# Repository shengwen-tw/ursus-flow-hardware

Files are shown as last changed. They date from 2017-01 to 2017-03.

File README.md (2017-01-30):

#Ursus-flow

This is the hardware design of Ursus-flow, a computer vision board provide speed estimation for multi-rotor.

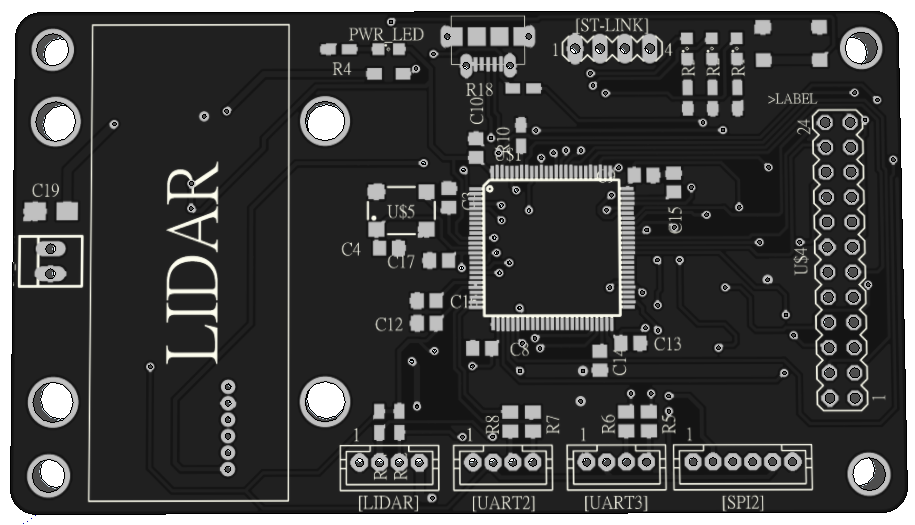
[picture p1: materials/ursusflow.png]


##Specification

**MCU**: STM32F745VETX

**Camera**: MT9v034 (I2C1 and DCMI)

**IMU**: MPU9250 (SPI1)

**Height sensor**: Lidar lite v2 (I2C2)

**USB**: Full Speed USB (USB2.0)

**EEPROM**: AT24C08 (I2C3)

UART2: Data output to flight control board

UART3 and SPI2: alternation

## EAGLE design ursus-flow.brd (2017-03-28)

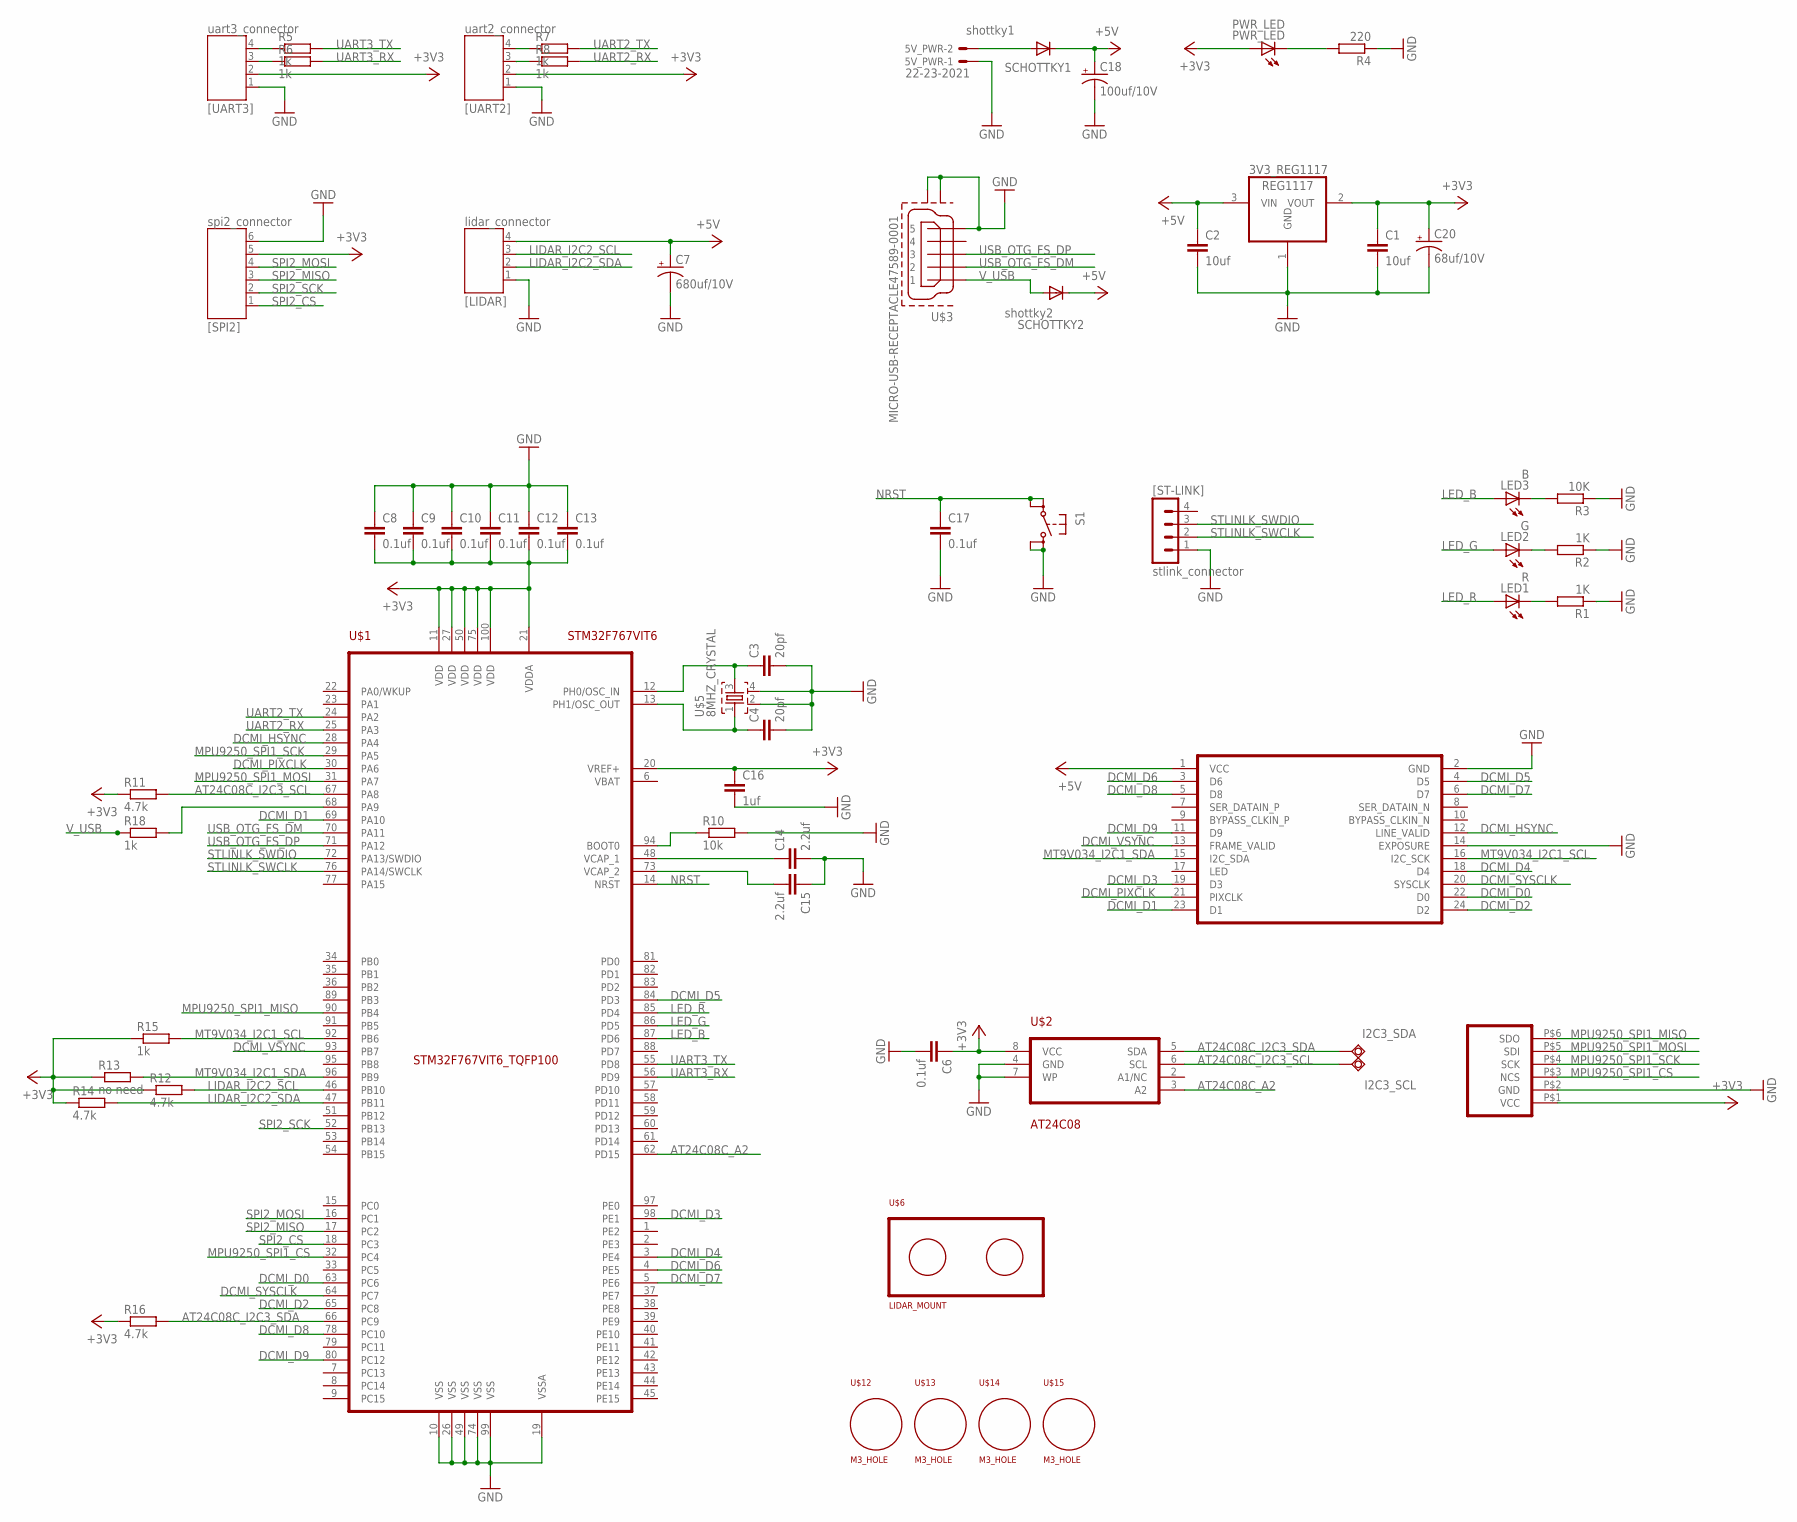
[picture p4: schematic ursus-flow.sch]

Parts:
3V3_REG1117: REG1117; SOT223
5V_PWR: 22-23-2021
C1, C2: 10uf; C0805K
C3, C4: 20pf; C0805
C6, C8, C9, C10, C11, C12, C13, C17: 0.1uf; C0805
C7: 680uf/10V; D/7343-31W
C14, C15: 2.2uf; C0805
C16: 1uf; C0805
C18: 100uf/10V; C/6032-28R
C20: 68uf/10V; B/3528-21W
I2C3_SCL, I2C3_SDA: TPSQTP20SQ; TP20SQ
LED1: R; SML0805
LED2: G; SML0805
LED3: B; SML0805
PWR_LED: PWR_LED; SML0805
R1, R2: 1K; R0805W
R3: 10K; R0805W
R4: 220; R0805W
R5, R6, R7, R8: 1k; M0805
R10: 10k; R0805W
R11, R12, R14, R16: 4.7k; R0805W
R13: no need; R0805W
R15, R18: 1k; R0805W
S1: EVQPSL/Q
SCHOTTKY1: shottky1; SOD323-W
SCHOTTKY2: shottky2; SOD323-W
U$1: STM32F767VIT6
U$2: AT24C08; SO8
U$3: MICRO-USB-RECEPTACLE47589-0001; 47589-0001
U$4: MT9V034_MODULE; MA12-2
U$5: 8MHZ_CRYSTAL
U$6: LIDAR_MOUNT
U$11: MPU9250_BREAKOUT
U$12, U$13, U$14, U$15: M3_HOLE
[LIDAR]: lidar_connector; JST-PH4
[SPI2]: spi2_connector; JST-PH6
[ST-LINK]: stlink_connector; MA04-1
[UART2]: uart2_connector; JST-PH4
[UART3]: uart3_connector; JST-PH4

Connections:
+3V3: 3V3_REG1117.2 (VOUT), C1.1, C6.1, C8.2, C9.2, C10.2, C11.2, C12.2, C13.2, C16.1, C20.+, PWR_LED.A, R11.1, R12.1, R13.1, R14.1, R15.1, R16.1, U$1.11 (VDD), U$1.20 (VREF+), U$1.21 (VDDA), U$1.27 (VDD), U$1.50 (VDD), U$1.75 (VDD), U$1.100 (VDD), U$2.8 (VCC), U$11.P$1 (VCC), [SPI2].5, [UART2].2, [UART3].2
+5V: 3V3_REG1117.3 (VIN), C2.1, C7.+, C18.+, SCHOTTKY1.C, SCHOTTKY2.C, U$4.1 (VCC), [LIDAR].4
AT24C08C_A2: U$1.62 (PD15), U$2.3 (A2)
AT24C08C_I2C3_SCL: I2C3_SCL.TP, R11.2, U$1.67 (PA8), U$2.6 (SCL)
AT24C08C_I2C3_SDA: I2C3_SDA.TP, R16.2, U$1.66 (PC9), U$2.5 (SDA)
DCMI_D0: U$1.63 (PC6), U$4.22 (D0)
DCMI_D1: U$1.69 (PA10), U$4.23 (D1)
DCMI_D2: U$1.65 (PC8), U$4.24 (D2)
DCMI_D3: U$1.98 (PE1), U$4.19 (D3)
DCMI_D4: U$1.3 (PE4), U$4.18 (D4)
DCMI_D5: U$1.84 (PD3), U$4.4 (D5)
DCMI_D6: U$1.4 (PE5), U$4.3 (D6)
DCMI_D7: U$1.5 (PE6), U$4.6 (D7)
DCMI_D8: U$1.78 (PC10), U$4.5 (D8)
DCMI_D9: U$1.80 (PC12), U$4.11 (D9)
DCMI_HSYNC: U$1.28 (PA4), U$4.12 (LINE_VALID)
DCMI_PIXCLK: U$1.30 (PA6), U$4.21 (PIXCLK)
DCMI_SYSCLK: U$1.64 (PC7), U$4.20 (SYSCLK)
DCMI_VSYNC: U$1.93 (PB7), U$4.13 (FRAME_VALID)
GND: 3V3_REG1117.1 (GND), 5V_PWR.1, C1.2, C2.2, C3.2, C4.2, C6.2, C7.-, C8.1, C9.1, C10.1, C11.1, C12.1, C13.1, C14.2, C15.1, C16.2, C17.2, C18.-, C20.-, R1.1, R2.1, R3.1, R4.1, R10.2, S1.B (S), S1.B1 (S1), U$1.10 (VSS), U$1.19 (VSSA), U$1.26 (VSS), U$1.49 (VSS), U$1.74 (VSS), U$1.99 (VSS), U$2.4 (GND), U$2.7 (WP), U$3.5, U$3.CASING1 (GND1), U$3.CASING2 (GND2), U$4.2 (GND), U$4.14 (EXPOSURE), U$5.2, U$5.4, U$11.P$2 (GND), [LIDAR].1, [SPI2].6, [ST-LINK].1, [UART2].1, [UART3].1
LED_B: LED3.A, U$1.87 (PD6)
LED_G: LED2.A, U$1.86 (PD5)
LED_R: LED1.A, U$1.85 (PD4)
LIDAR_I2C2_SCL: R12.2, U$1.46 (PB10), [LIDAR].3
LIDAR_I2C2_SDA: R14.2, U$1.47 (PB11), [LIDAR].2
MPU9250_SPI1_CS: U$1.32 (PC4), U$11.P$3 (NCS)
MPU9250_SPI1_MISO: U$1.90 (PB4), U$11.P$6 (SDO)
MPU9250_SPI1_MOSI: U$1.31 (PA7), U$11.P$5 (SDI)
MPU9250_SPI1_SCK: U$1.29 (PA5), U$11.P$4 (SCK)
MT9V034_I2C1_SCL: R15.2, U$1.92 (PB6), U$4.16 (I2C_SCK)
MT9V034_I2C1_SDA: R13.2, U$1.96 (PB9), U$4.15 (I2C_SDA)
unnamed: LED1.C, R1.2
unnamed: LED2.C, R2.2
unnamed: LED3.C, R3.2
unnamed: PWR_LED.C, R4.2
unnamed: 5V_PWR.2, SCHOTTKY1.A
unnamed: C3.1, U$1.12 (PH0/OSC_IN), U$5.3
unnamed: R5.1, [UART3].4
unnamed: R6.1, [UART3].3
unnamed: R7.1, [UART2].4
unnamed: R8.1, [UART2].3
unnamed: C4.1, U$1.13 (PH1/OSC_OUT), U$5.1
unnamed: C14.1, U$1.48 (VCAP_1)
unnamed: C15.2, U$1.73 (VCAP_2)
unnamed: R10.1, U$1.94 (BOOT0)
unnamed: R18.2, U$1.68 (PA9)
NRST: C17.1, S1.A, S1.A1 (P1), U$1.14 (NRST)
SPI2_CS: U$1.18 (PC3), [SPI2].1
SPI2_MISO: U$1.17 (PC2), [SPI2].3
SPI2_MOSI: U$1.16 (PC1), [SPI2].4
SPI2_SCK: U$1.52 (PB13), [SPI2].2
STLINLK_SWCLK: U$1.76 (PA14/SWCLK), [ST-LINK].2
STLINLK_SWDIO: U$1.72 (PA13/SWDIO), [ST-LINK].3
UART2_RX: R8.2, U$1.25 (PA3)
UART2_TX: R7.2, U$1.24 (PA2)
UART3_RX: R6.2, U$1.56 (PD9)
UART3_TX: R5.2, U$1.55 (PD8)
USB_OTG_FS_DM: U$1.70 (PA11), U$3.2
USB_OTG_FS_DP: U$1.71 (PA12), U$3.3
V_USB: R18.1, SCHOTTKY2.A, U$3.1

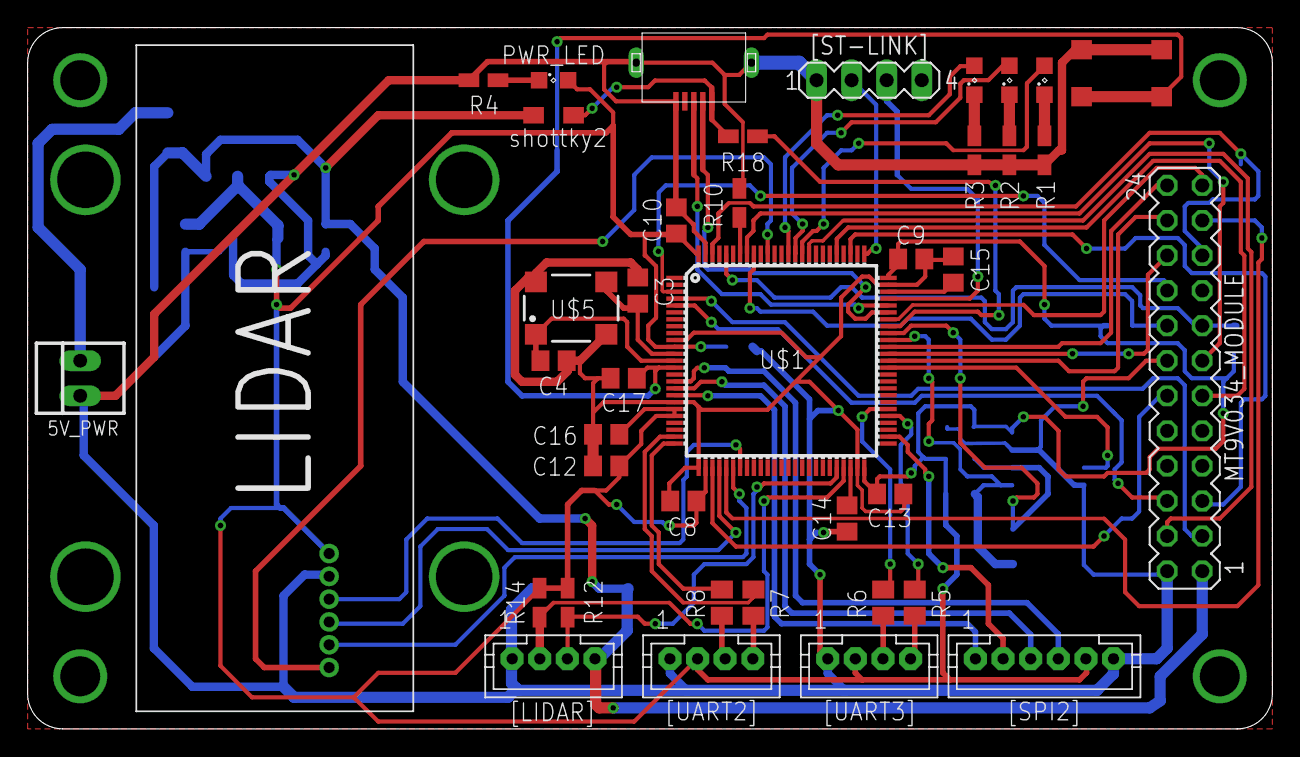
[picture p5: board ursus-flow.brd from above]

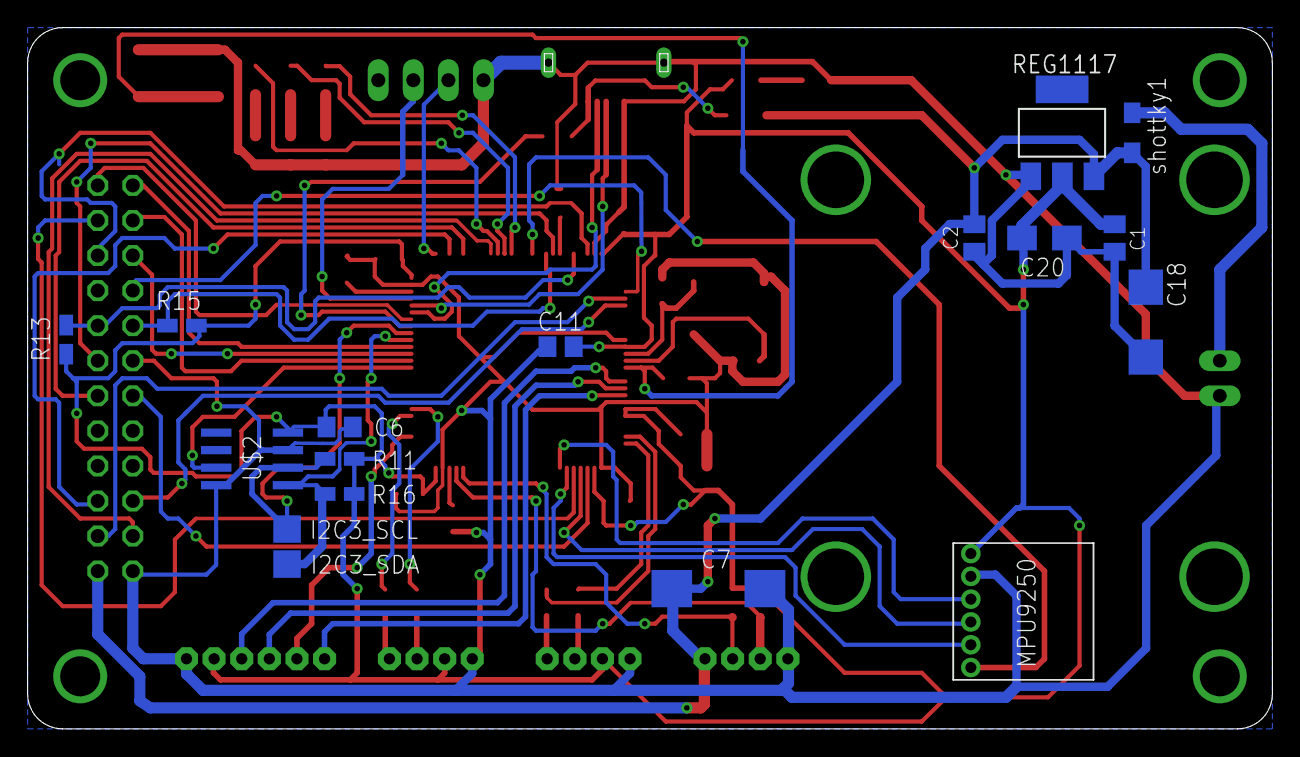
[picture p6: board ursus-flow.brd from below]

Board: 2 copper layers, 90.2 x 50.8 mm, 61 parts (17 on the bottom side), 60 nets.

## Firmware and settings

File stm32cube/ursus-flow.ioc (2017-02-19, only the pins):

Mcu.UserName=STM32F767VITx
PA10.Signal=DCMI_D1
PA11.Signal=USB_OTG_FS_DM
PA12.Signal=USB_OTG_FS_DP
PA13.GPIO_Label=STLINK-SWDIO
PA13.Signal=SYS_JTMS-SWDIO
PA14.GPIO_Label=STLINK-SWCLK
PA14.Signal=SYS_JTCK-SWCLK
PA2.Signal=USART2_TX
PA3.Signal=USART2_RX
PA4.Signal=DCMI_HSYNC
PA5.GPIO_Label=MPU9250_SPI1_SCK
PA5.Signal=SPI1_SCK
PA6.Signal=DCMI_PIXCLK
PA7.GPIO_Label=MPU9250_SPI1_MOSI
PA7.Signal=SPI1_MOSI
PA8.GPIO_Label=AT24C08C_I2C3_SCL
PA8.Signal=I2C3_SCL
PA9.Signal=USB_OTG_FS_VBUS
PB10.GPIO_Label=LIDAR_I2C2_SCL
PB10.Signal=I2C2_SCL
PB11.GPIO_Label=LIDAR_I2C2_SDA
PB11.Signal=I2C2_SDA
PB13.Signal=SPI2_SCK
PB4.GPIO_Label=MPU9250_SPI1_MISO
PB4.Signal=SPI1_MISO
PB6.GPIO_Label=MT9V034_I2C1_SCL
PB6.Signal=I2C1_SCL
PB7.Signal=DCMI_VSYNC
PB9.GPIO_Label=MT9V034_I2C1_SDA
PB9.Signal=I2C1_SDA
PC1.Signal=SPI2_MOSI
PC10.Signal=DCMI_D8
PC12.Signal=DCMI_D9
PC2.Signal=SPI2_MISO
PC3.GPIO_Label=SPI2_CS
PC3.Signal=GPIO_Output
PC4.GPIO_Label=MPU9250_SPI1_CS
PC4.Signal=GPIO_Output
PC6.Signal=DCMI_D0
PC7.GPIO_Label=DCMI_SYSCLK
PC7.Signal=S_TIM8_CH2
PC8.Signal=DCMI_D2
PC9.GPIO_Label=AT24C08C_I2C3_SDA
PC9.Signal=I2C3_SDA
PD3.Signal=DCMI_D5
PD4.GPIO_Label=LED_R
PD4.Signal=GPIO_Output
PD5.GPIO_Label=LED_G
PD5.Signal=GPIO_Output
PD6.GPIO_Label=LED_B
PD6.Signal=GPIO_Output
PD8.Signal=USART3_TX
PD9.Signal=USART3_RX
PE1.Signal=DCMI_D3
PE4.Signal=DCMI_D4
PE5.Signal=DCMI_D6
PE6.Signal=DCMI_D7
PH0/OSC_IN.Signal=RCC_OSC_IN
PH1/OSC_OUT.Signal=RCC_OSC_OUT

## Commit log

2016-12-21 Create new eagle project
    [ursus-flow.sch]
2016-12-21 Add STM32CubeMX project
2016-12-23 Save circuit 2016/12/24
    [ursus-flow.sch]
2016-12-24 Save 2016/12/24
    [ursus-flow.sch]
2016-12-24 Save 2016/12/25 Happy Christmas
    [ursus-flow.sch]
2016-12-25 Fix diode and connector
    [ursus-flow.sch]
2016-12-30 2016/12/30 Good bye 2016
    [ursus-flow.brd, ursus-flow.sch]
2017-01-04 Add MPU9250 breakout board
    [ursus-flow.brd, ursus-flow.sch]
2017-01-27 Update MT9V034 and MPU9250
    [ursus-flow.brd, ursus-flow.sch]
2017-01-27 Arrange components
    [ursus-flow.brd, ursus-flow.sch]
2017-01-27 Remove wrong footprint of MPU9250
    [ursus-flow.brd, ursus-flow.sch]
2017-01-28 Start doing PCB layout
    [ursus-flow.brd, ursus-flow.sch]
2017-01-28 Keep routing
    [ursus-flow.brd]
2017-01-28 Layout is almost done
    [ursus-flow.brd]
2017-01-28 Connect more traces
    [ursus-flow.brd]
2017-01-30 Finish PCB layout
    [ursus-flow.brd, ursus-flow.sch]
2017-01-30 Fix small errors
    [ursus-flow.brd]
2017-01-30 Adjust labels
    [ursus-flow.brd]
2017-02-01 Add IMU logo
    [ursus-flow.brd]
2017-02-01 Adjust MPU9250 drill size
    [ursus-flow.brd, ursus-flow.sch]
2017-02-19 Do circuit final check
    [ursus-flow.brd, ursus-flow.sch]
2017-02-19 Adjust logo
    [ursus-flow.brd]
2017-02-20 Remove trash dove
    [ursus-flow.brd]
2017-03-19 Update component value
    [ursus-flow.brd, ursus-flow.sch]
2017-03-28 Update pull up resistors for mt9v034
    [ursus-flow.brd, ursus-flow.sch]

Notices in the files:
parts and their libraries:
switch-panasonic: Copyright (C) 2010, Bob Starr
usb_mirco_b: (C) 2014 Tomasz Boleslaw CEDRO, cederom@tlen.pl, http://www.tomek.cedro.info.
